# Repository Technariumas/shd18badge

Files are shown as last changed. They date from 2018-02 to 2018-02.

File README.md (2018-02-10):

# Science Hack Day Vilnius 2018 - badge

Participant badge for Science Hack Day Vilnius 2018

## Prerequisites

To use the badge, you will need the following:

 * A laptop with Linux, Mac OS or Windows and at least one free USB port.
 * If it’s Windows or Mac OS, make sure to install [drivers](https://wiki.wemos.cc/downloads) for the CH340 UBS2TTL chip.
 * A micro-USB cable with data lines that fits your USB port.
 * You will need a terminal application installed. For Linux and Mac you can use screen, which is installed by default. For Windows we recommend [PuTTy](http://www.chiark.greenend.org.uk/~sgtatham/putty/download.html) or [CoolTerm](http://freeware.the-meiers.org/).
 * Please note that the workshop will be in English.

## Schematics



## Programming

Use dmesg to determine the USB port the badge is connected to, e.g. /dev/ttyUSB0.

Flash the firmware:
cd shd18badge/micropython

Edit the flash_microcontroller.sh file so that it points to the correct USB port. If esptool.py is needed, install it (for example, pip install esptool.py). Then copy the Python files to the microcontroller:

python transfer_files.py -p /dev/ttyUSB5 -b 115200 util.py main.py thermistor.py boot.py
 
## Tutorial
 * A pretty great [tutorial is available here](http://docs.micropython.org/en/latest/esp8266/esp8266/tutorial/index.html)
 * [A MAC user first hand experience](MACUSERS.md) using the badge

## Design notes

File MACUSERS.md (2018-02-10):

## Experiences of a mac user getting the Tardigrade set up

1. Install drivers as per [the README](README.md). 
2. Open a terminal, plug the tardigrade in to your computer, and run `sudo dmesg` in the terminal. 
3. You should see a line like this, or something similar: `wch_usb detach. provider USB2.0-Serial.` - if not, unplug the tardigrade and plug it back in again before re-running `sudo dmesg`.
4. We now know we're looking for a device called wch_usb. run `ls /dev/tty.wchusb` and press tab to get the exact device name. It might be `/dev/tty.wchusbserial1410`.
5. Ok, we're ready to connect to the device! We'll open a session using the program called *screen*. Type `screen /dev/tty.wchusbyourdevice here  115200` - for me it was `screen /dev/tty.wchusbserial1410  115200`. 
6. After a few seconds, you should start seeing the temperature being output continuously to the screen now. Try putting your finger on the temperatures sensor (bottom middle of the tardigrade on the LED side) and watch the numbers change!
7. Press ctrl+c on your keyboard to stop the temperature output. Now you'll have a command prompt where you can type commands to your tardigrade. 
8. Try some commands like `flash(200)`, `getTemperature`, `setPixel(255,0,100)`, `setLeds(0b10101010)`, or `wigglefeet`. You can see the full list here: https://github.com/Technariumas/shd18badge/blob/master/micropython/main.py 

Some more tips:

- press ctrl+d to start the temperature readings again
- press ctrl+a+d to detach from the screen session and get your terminal window back.
- if you want to go back to the screen session and you haven't unplugged your tardigrade, type `screen -dr` to start playing with your tardigrade again. 

## setLeds:

You'll always need to leave 0b there, but try changing `01010101` to something else - there's one number for each tardigrade foot, and you can switch them all off by setting them to 0, e.g. `setLeds(0b00000000)`. Can you guess how to turn them all on?

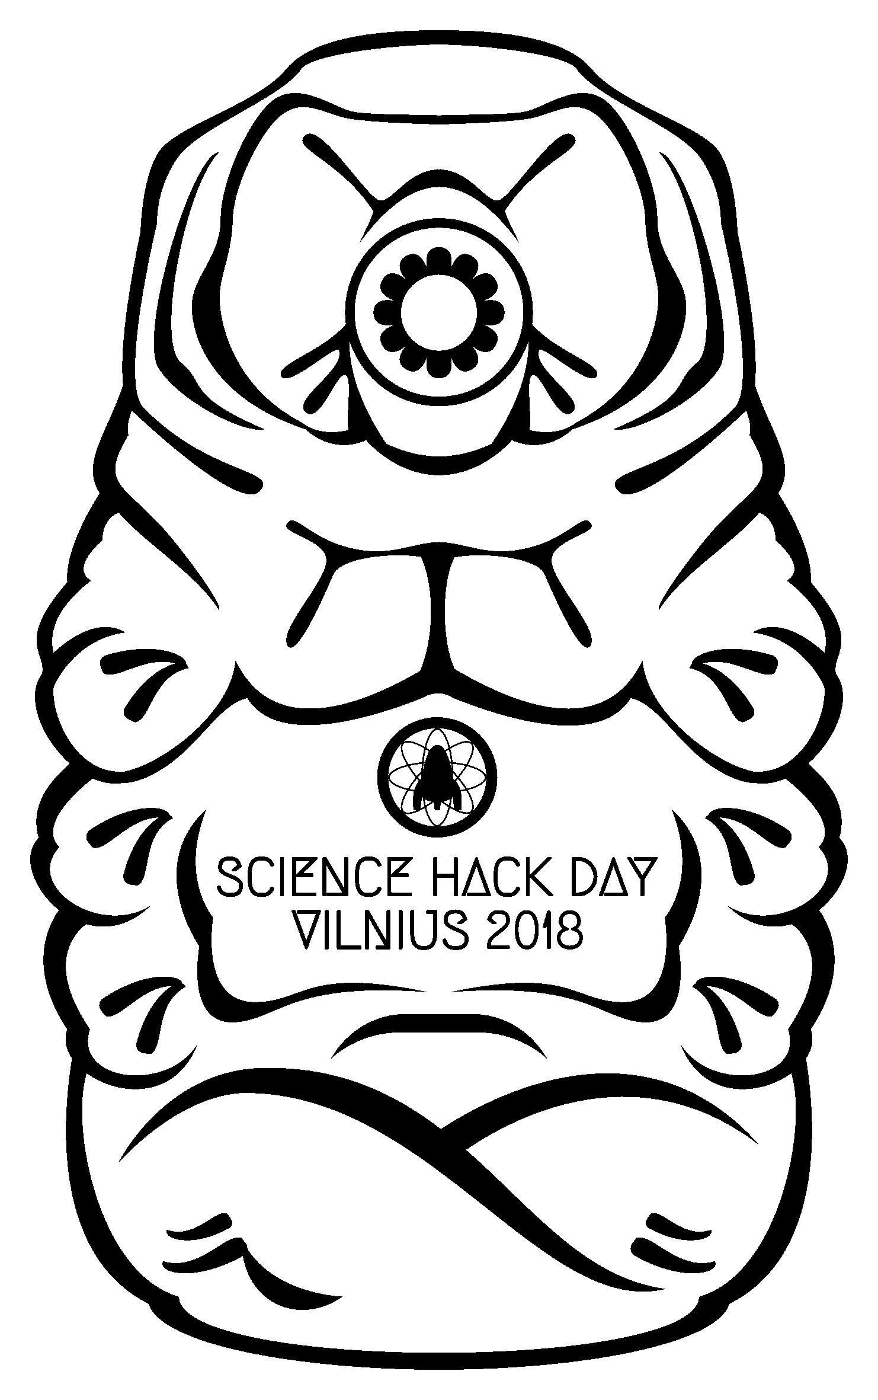
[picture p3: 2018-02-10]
letunai-10.svg.png

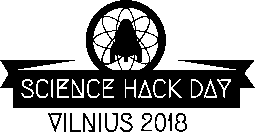
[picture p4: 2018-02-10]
g10385.png

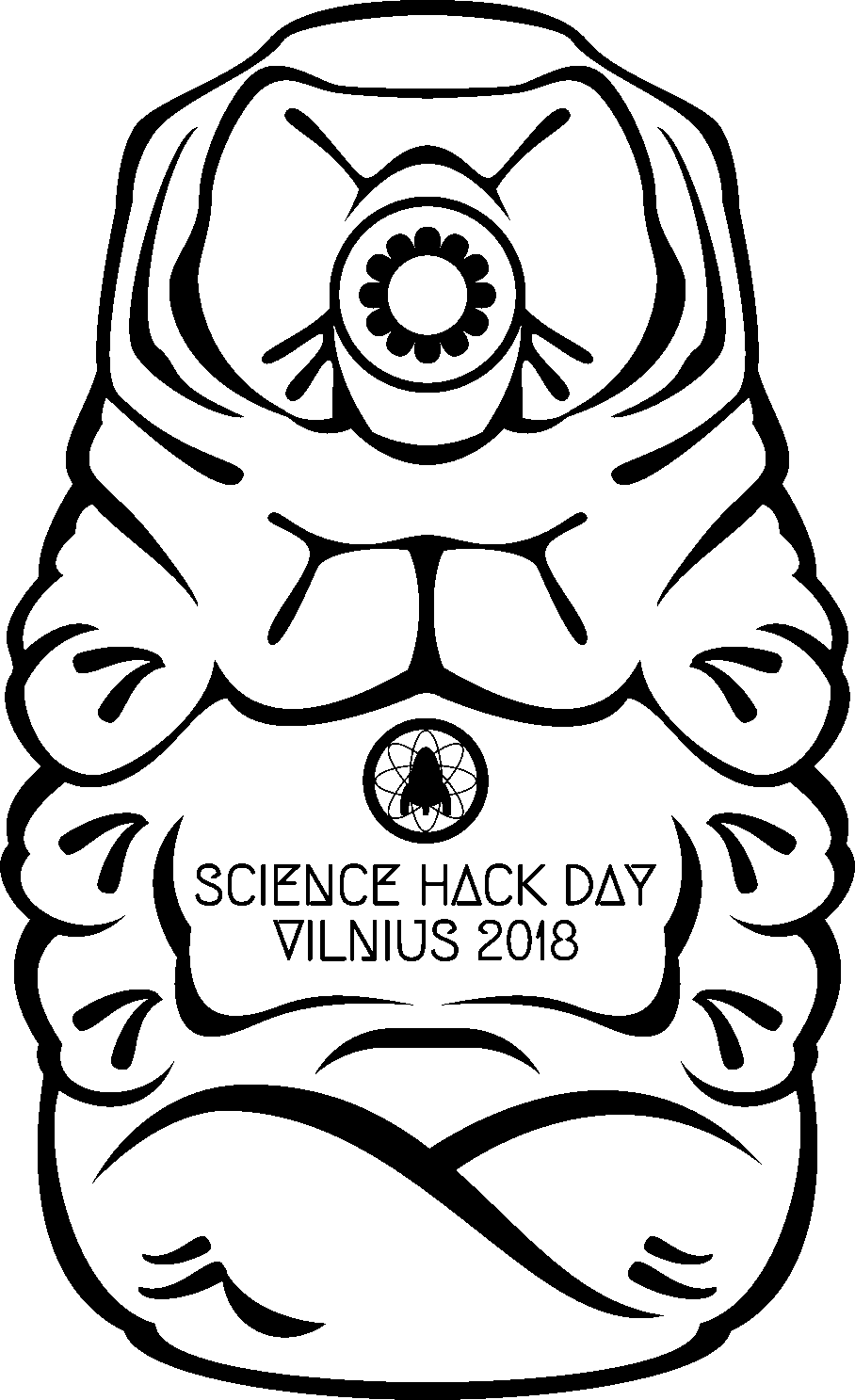
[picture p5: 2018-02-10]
letunas-10.png

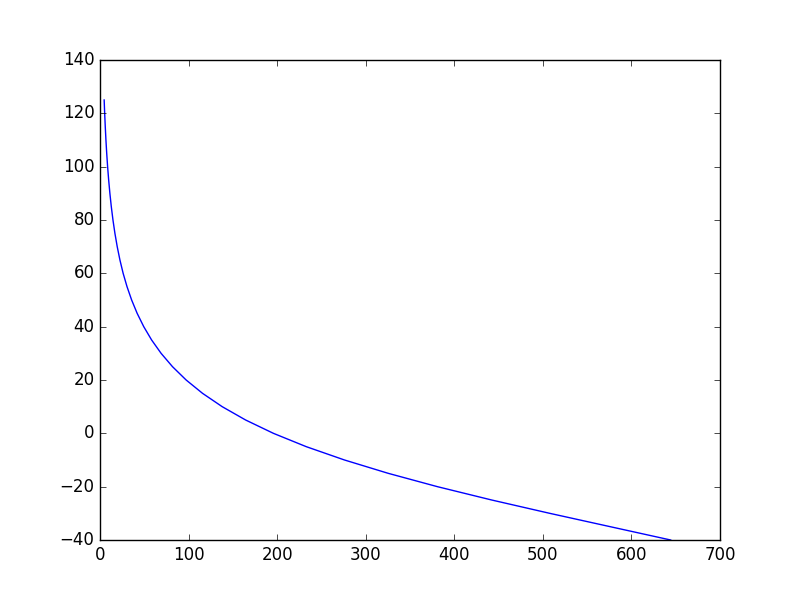
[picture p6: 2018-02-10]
micropython/adc-vs-temp.png

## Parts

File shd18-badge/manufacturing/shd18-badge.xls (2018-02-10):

Reference | Quantity | Value | Footprint | Datasheet | PartNo | Manufacturer | Distributor | Notes
BT1 | 1 | Battery | Battery_Holders:Keystone_2479_3xAAA |  | BH-2479 | ? | ?
C1 C2 | 2 | 1u | Capacitors_SMD:C_0603 |  | ? | ? | ? | 10V 1uF 0603
D1 D2 D3 D4 D5 D6 D7 D8 | 8 | LED | LEDs:LED_0603 |  | 19-217SUGC/TR8 | ? | ? | High brightness green led
LED1 | 1 | WS2812B | LEDs:LED_WS2812B-PLCC4 | http://www.world-semi.com/uploads/soft/150522/1-150522091P5.pdf | WS2812B | ? | ?
MK1 | 1 | Mounting_Hole | Mounting_Holes:MountingHole_3.2mm_M3 |  | ? | ? | ? | DNP
R1 | 1 | R | Resistors_SMD:R_0603 |  | ? | ? | ? | 1.00%
R10 R2 R3 R4 R5 R6 R7 R8 R9 | 9 | 1k | Resistors_SMD:R_0603 |  | ? | ? | ? | 1.00%
SW1 | 1 | SW_SPDT | wemos:SWITCH-SPST-SMD-A |  | ? | ? | ?
SW2 | 1 | SW_Push | wemos:4P-SMD-6.2X6.2X4H |  | ? | ? | ?
TH1 | 1 | Thermistor | Resistors_SMD:R_0603 |  | ? | ? | ? | 10k thermistor
U1 | 1 | WeMos_mini | wemos:D1_mini_board | https://wiki.wemos.cc/products:d1:d1_mini | ? | ? | ? | Wemos Mini board, use female headers.
U2 | 1 | 74HC595 | Housings_SOIC:SOIC-16_3.9x9.9mm_Pitch1.27mm | http://www.nxp.com/documents/data_sheet/74HC_HCT595.pdf | ? | ? | ? | Power voltage range down to 2V or lower

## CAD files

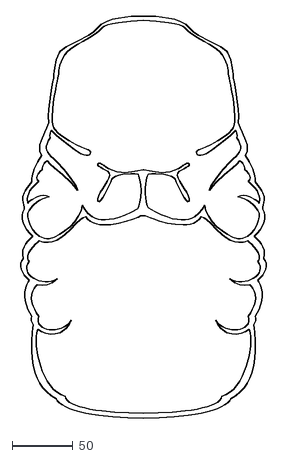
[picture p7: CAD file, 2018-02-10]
drawing1.dxf
209.5 x 330.9

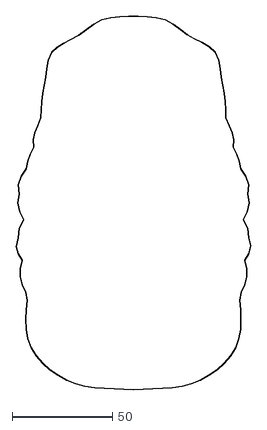
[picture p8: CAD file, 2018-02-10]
ooo.dxf
117.0 x 186.5

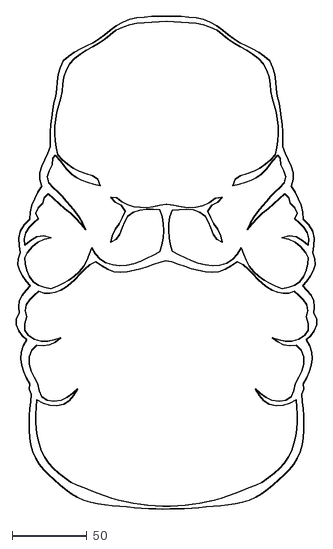
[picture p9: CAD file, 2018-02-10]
outline2.dxf
201.5 x 330.5

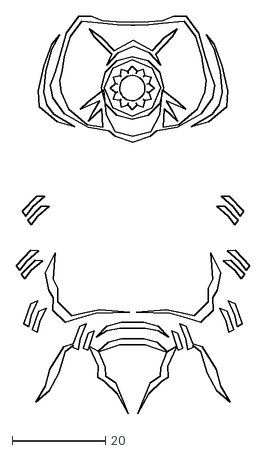
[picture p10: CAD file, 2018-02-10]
kisakita-10.dxf
50.2 x 85.5

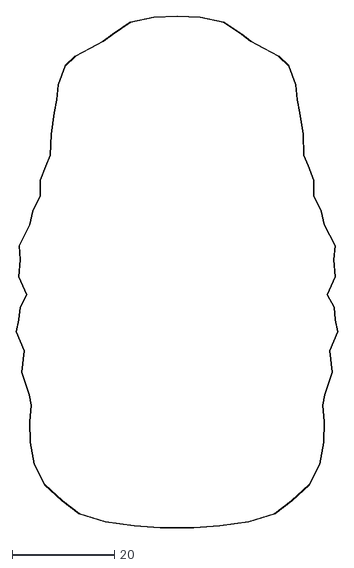
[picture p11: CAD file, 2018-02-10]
outline-10.dxf
62.9 x 100.3

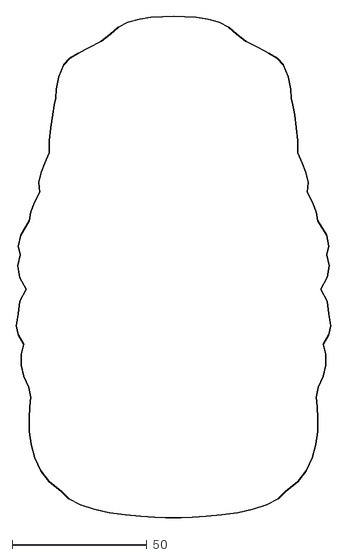
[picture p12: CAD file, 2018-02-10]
outline.dxf
116.6 x 185.7

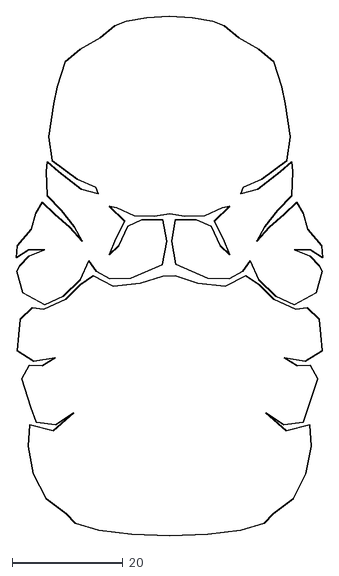
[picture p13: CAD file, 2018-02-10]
raukai-10.dxf
55.3 x 93.7

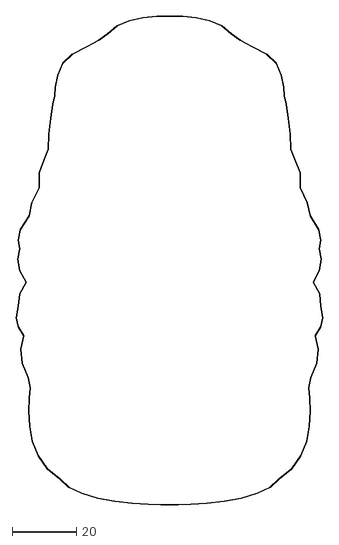
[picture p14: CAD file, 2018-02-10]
outline-10-1.dxf
95.6 x 152.4

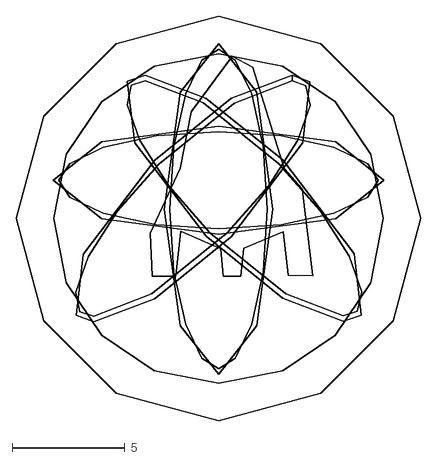
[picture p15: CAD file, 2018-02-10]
raketa.dxf
17.9 x 17.9

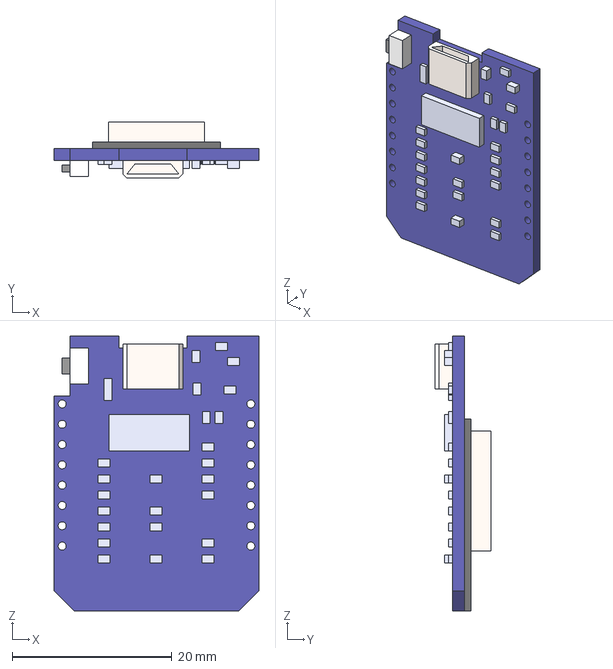
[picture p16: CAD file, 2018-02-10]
WEMOS D1 mini.step
25.6 x 7.00 x 34.4 mm

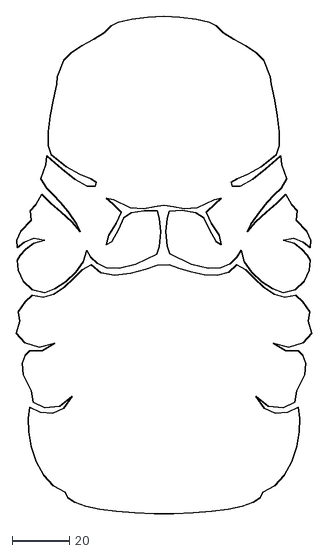
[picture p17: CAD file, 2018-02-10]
raukai.dxf
103.0 x 173.5

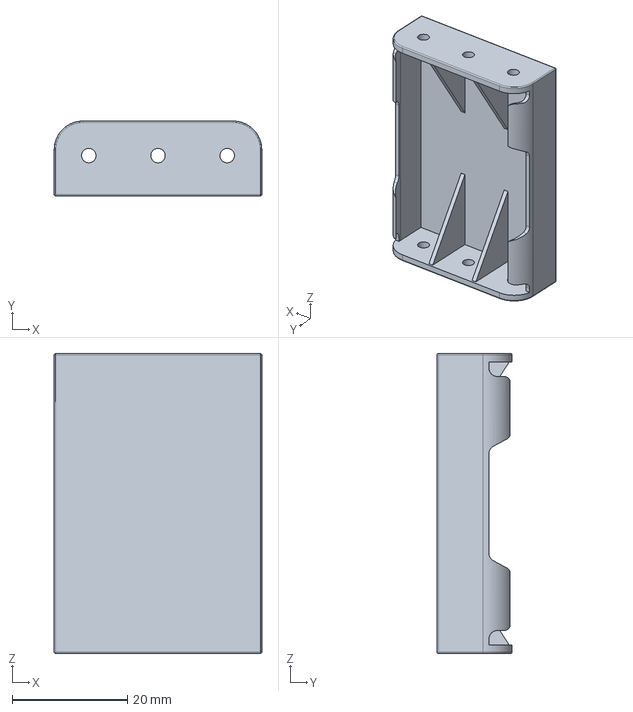
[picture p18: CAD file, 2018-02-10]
3x AAA battery holder.stp
36.0 x 13.0 x 52.0 mm

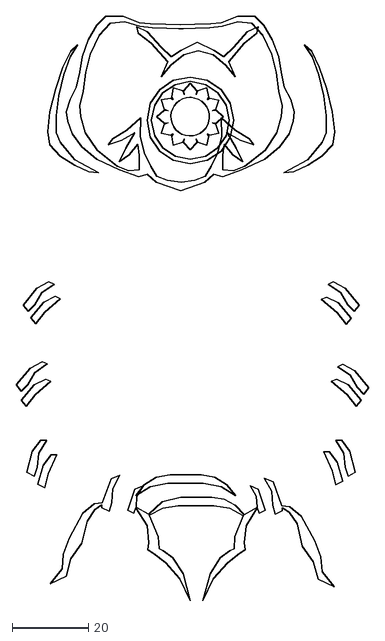
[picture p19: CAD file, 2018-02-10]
kisakita.dxf
92.1 x 152.9

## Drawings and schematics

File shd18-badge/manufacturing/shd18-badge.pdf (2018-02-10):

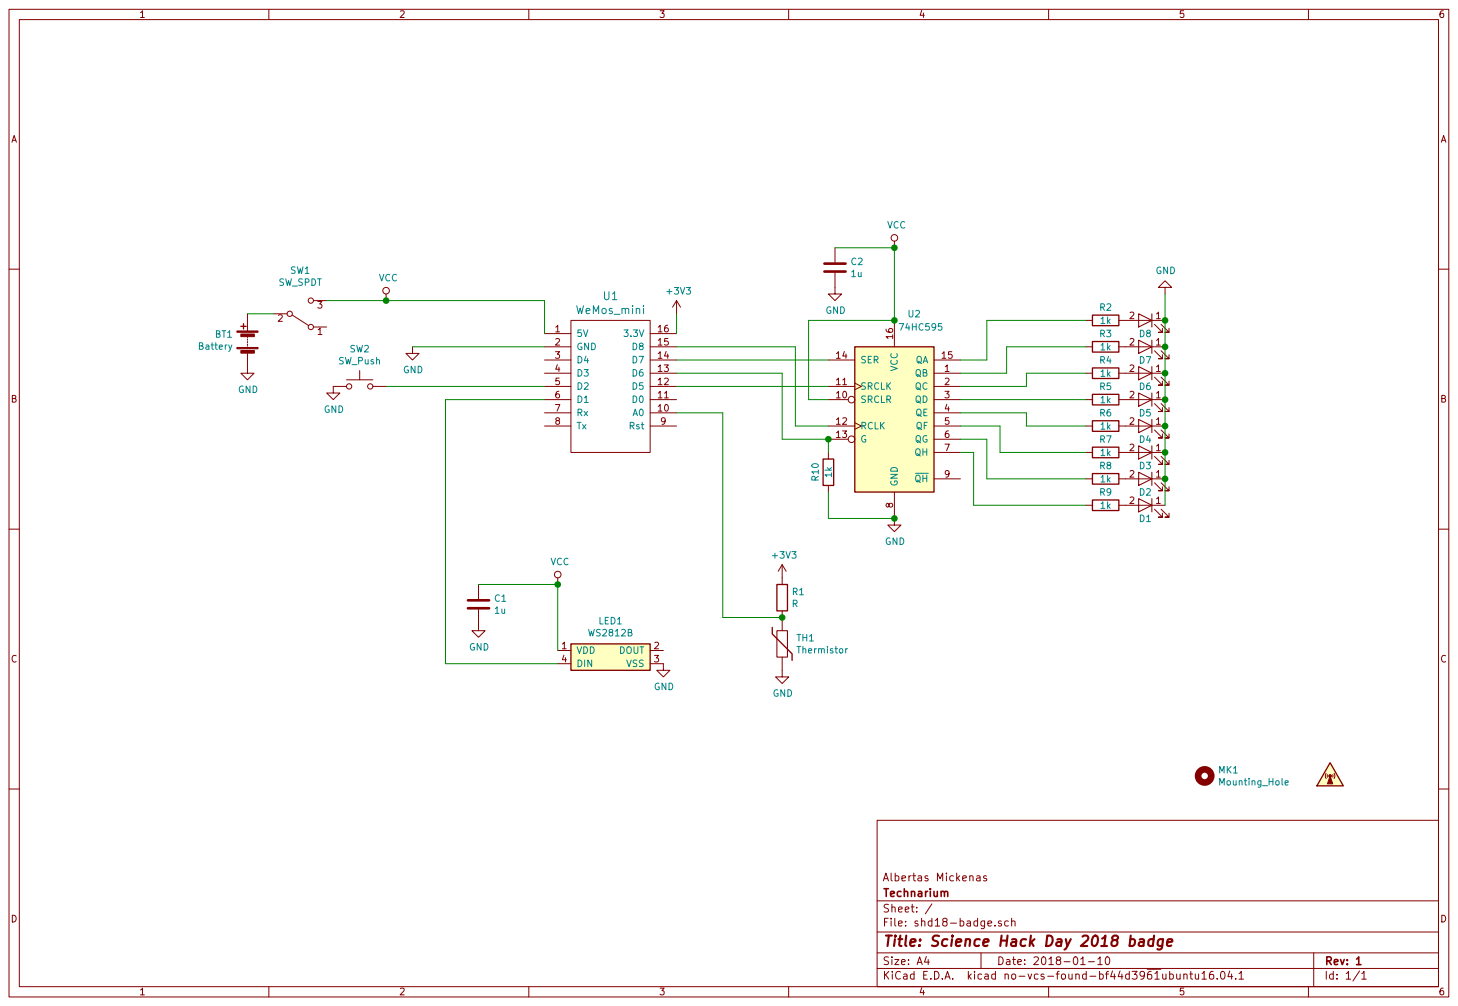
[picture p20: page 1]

8 QH 9 SRCLR 10 SRCLK 11 RCLK 12 G

Albertas Mickenas
File: shd18-badge.sch Sheet: / Technarium

Id: 1/1 Title: Science Hack Day 2018 badge

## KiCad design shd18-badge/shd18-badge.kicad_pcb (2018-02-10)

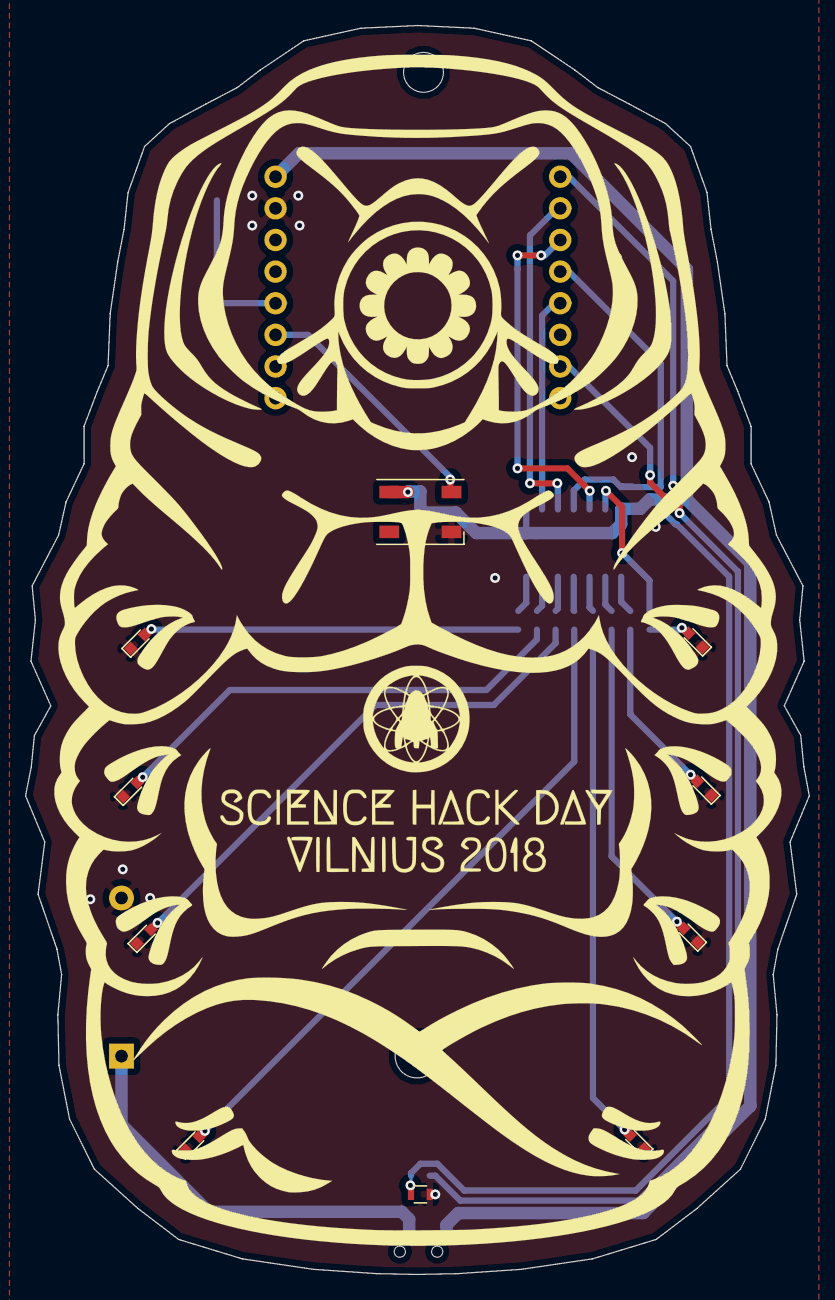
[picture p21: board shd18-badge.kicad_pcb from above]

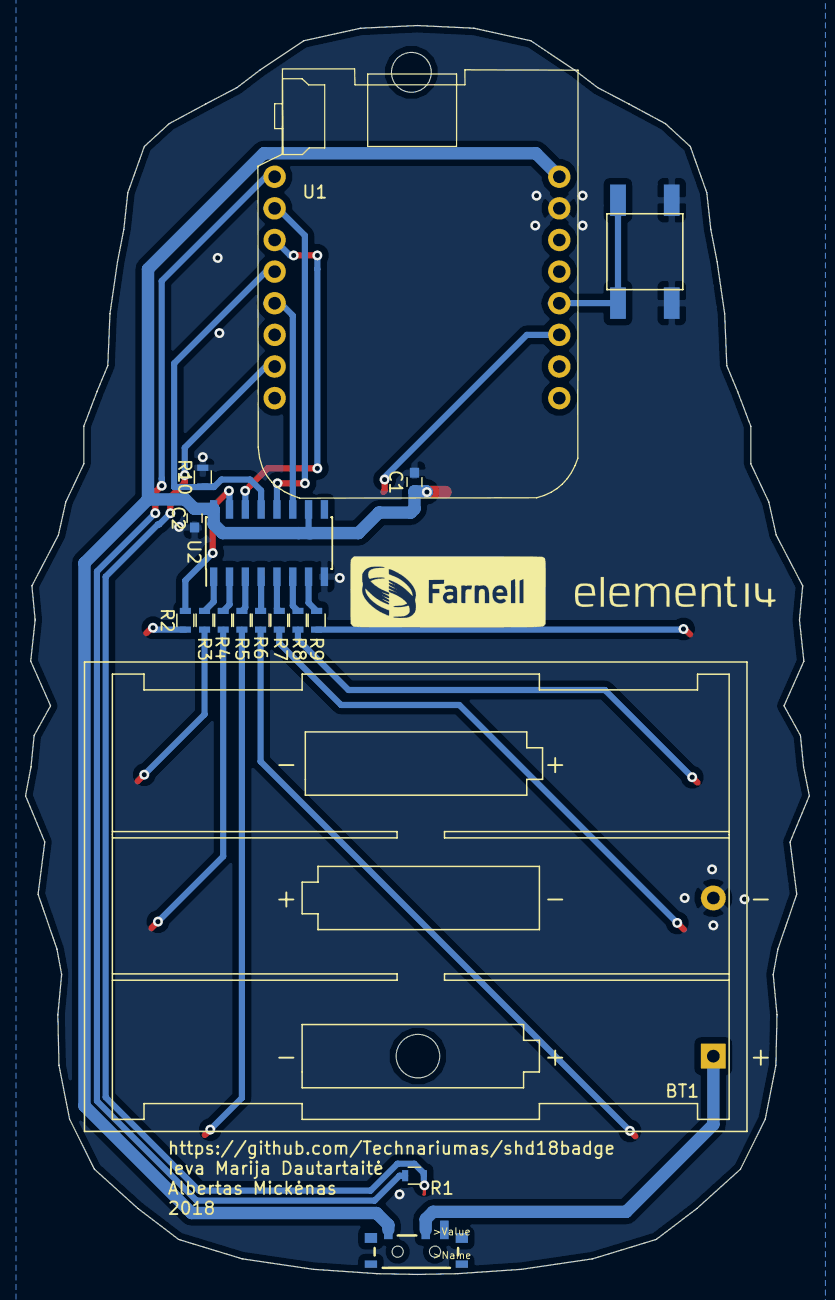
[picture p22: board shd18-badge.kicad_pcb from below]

Board: 2 copper layers, 62.9 x 100.3 mm, 28 parts (17 on the bottom side), 27 nets.

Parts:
BT1: Battery; Keystone_2479_3xAAA
C1, C2: 1u; C_0603
D1, D2, D3, D4, D5, D6, D7, D8: LED; LED_0603
LED1: WS2812B; LED_WS2812B-PLCC4
MK1: Mounting_Hole; MountingHole_3.2mm_M3
R1: R; R_0603
R2, R3, R4, R5, R6, R7, R8, R9, R10: 1k; R_0603
SW1: SW_SPDT; SWITCH-SPST-SMD-A
SW2: SW_Push; 4P-SMD-6.2X6.2X4H
TH1: Thermistor; R_0603
U1: WeMos_mini; D1_mini_board
U2: 74HC595; SOIC-16_3.9x9.9mm_Pitch1.27mm

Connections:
+3V3: R1.1, U1.16
GND: BT1.2, C1.2, C2.2, D1.1, D2.1, D3.1, D4.1, D5.1, D6.1, D7.1, D8.1, LED1.3, R10.2, SW2.1, TH1.2, U1.2, U2.8
unnamed: BT1.1, SW1.2
unnamed: D1.2, R9.1
unnamed: D2.2, R8.1
unnamed: D3.2, R7.1
unnamed: D4.2, R6.1
unnamed: D5.2, R5.1
unnamed: D6.2, R4.1
unnamed: D7.2, R3.1
unnamed: D8.2, R2.1
unnamed: LED1.4, U1.6
unnamed: R1.2, TH1.1, U1.10
unnamed: R2.2, U2.15
unnamed: R3.2, U2.1
unnamed: R4.2, U2.2
unnamed: R5.2, U2.3
unnamed: R6.2, U2.4
unnamed: R7.2, U2.5
unnamed: R8.2, U2.6
unnamed: R9.2, U2.7
unnamed: R10.1, U1.13, U2.13
unnamed: SW2.2, U1.5
unnamed: U1.12, U2.11
unnamed: U1.14, U2.14
unnamed: U1.15, U2.12
VCC: C1.1, C2.1, LED1.1, SW1.3, U1.1, U2.10, U2.16

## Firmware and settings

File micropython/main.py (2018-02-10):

from machine import Pin, SPI, ADC
from neopixel import NeoPixel
from time import sleep
import thermistor
import urandom
import util


pixel = NeoPixel(Pin(5, Pin.OUT), 1)
spi = SPI(1, baudrate=1000000, polarity=0, phase=0)
cs=Pin(15, Pin.OUT)
thermistorAdc = ADC(0)
button = Pin(4, Pin.IN, Pin.PULL_UP)

def setPixel(r, g, b):
	pixel[0] = (r, g, b)
	pixel.write()         

def setLeds(b):
	cs.off();
	spi.write(bytearray([b]))
	cs.on();

def getTemperature():
	return thermistor.lsbToTemperature(thermistorAdc.read())



def wiggleFeet():
	for t in range(10):
		setLeds(0x55)
		sleep(0.07)
		setLeds(0xAA)
		sleep(0.07)
	setLeds(0)

def cycleFeet():
	for t in range(8):
		setLeds(1 << t)
		sleep(0.1)


def flash(color):
	if None == color:
		color = urandom.getrandbits(8)
	(r, g, b) = util.colorWheel(color)
	setPixel(r, g, b)
	while r > 0 or g > 0 or b > 0:
		if r > 0:
			r = r - 1
		if g > 0:
			g = g - 1
		if b > 0:
			b = b - 1
		setPixel(r, g, b)
		sleep(0.01)

setPixel(0, 0, 0)
wiggleFeet()
flash(None)
cycleFeet()
cycleFeet()
cycleFeet()


temp = getTemperature()
MODE1 = 1
MODE2 = 2

mode = MODE1

while True:
	print(getTemperature())

	if MODE1 == mode:
		if abs(getTemperature() - temp) > 1:
			flash(int(util.translate(temp, 5, 30, 0, 255)))
			sleep(0.1)
			temp = getTemperature()
		setLeds(urandom.getrandbits(8))
		sleep(0.01)
	elif MODE2 == mode:
		temp = getTemperature()
		(r,g,b) = util.colorWheel(int(util.translate(temp, 5, 30, 0, 255)))
		setPixel(r, g, b)
		cycleFeet()

	if 0 == button.value():
		setPixel(0,0,0)
		setLeds(0)
		if mode < MODE2:
			mode = mode + 1
		else:
			mode = MODE1
		while 0 == button.value():
			print(button.value())

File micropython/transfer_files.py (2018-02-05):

import websocket
import serial
import sys
import time
import os
import binascii
import tqdm


CHUNK_SIZE = 50
TEST_PY = False


def ctrl(key):
    return chr(ord(key.upper()) - ord('A') + 1)



class EspSerial(serial.Serial):
    DEFAULT_DELAY = .1
    def command(self, data='', delay=None):
        delay = delay or self.DEFAULT_DELAY
        self.write(data + '\r')
        time.sleep(delay)
        res = self.read(self.inWaiting())
        #sys.stdout.write(res)
        print 'RES', repr(res)
        return res

    def reset_esp(self):
        self.write(ctrl('c'))
        self.command(ctrl('d'), 1.5)
        self.command()
        assert not self.command().endswith('>>> '), 'Bad reset!'

    def prepare_transfer(self):
        self.write(ctrl('c'))
        self.command('import ubinascii')
        self.write(ctrl('e'))
        self.write('def w(d):\n')
        self.write('    return f.write(ubinascii.a2b_base64(d))\n')
        self.write(ctrl('d'))
        self.command()
    
    def transfer_chunk(self, chunk):
        assert len(chunk) <= CHUNK_SIZE, 'Chunk is too big!'
        return '...' not in self.command("w('%s')" % binascii.b2a_base64(chunk))


#class EspWebSocket(websocket.WebSocket, MyEsp):
#    DEFAULT_DELAY = 0
#
#    write = websocket.WebSocket.send
#    read_all = websocket.WebSocket.recv
#
#    def __init__(self, url, password):
#        super(EspWebSocket, self).__init__()
#        self.connect(url)
#        self.read_all()
#        self.command(password)


def work(sources, webrepl_url, webrepl_password, uart_port_name, uart_baud=115200):
    try:
#        if webrepl_url:
#            port = EspWebSocket(webrepl_url, webrepl_password)
#        else:
        port = EspSerial(uart_port_name, uart_baud)

        #print 'Performing reset...'
        #port.reset_esp()

        print 'Preparing...'
        port.prepare_transfer()

        for source_path in sources:
            dest_path = os.path.split(source_path)[1]
            try:
                port.command("f = open('%s', 'wb')" % dest_path)

                progress_bar = tqdm.tqdm(ncols=100, desc=source_path, total=os.stat(source_path).st_size, unit='B', unit_scale=True)

                with open(source_path, 'rb') as in_f:
                    while True:
                        buf = in_f.read(CHUNK_SIZE)
                        if not buf:
                            break
                        if not port.transfer_chunk(buf):
                            # TODO: Try again with higher command delay
                            progress_bar.close()
                            print '%s FAILED!' % source_path
                            port.write('\x03')
                            break
                        progress_bar.update(len(buf))
            except Exception as e:
                print e
            finally:
                progress_bar.close()
                port.command('f.close()')
    except Exception as e:
        print e
    finally:
        time.sleep(1)
        port.reset_esp()
        port.close()

    print 'Done.'


def main():
    import argparse

    parser = argparse.ArgumentParser()

    parser.add_argument('-u', '--url', help='WebREPL URL')
    parser.add_argument('-w', '--password', help='WebREPL password')
    parser.add_argument('-p', '--port', help='UART port name')
    parser.add_argument('-b', '--baud', help='UART baud rate', type=int, default=115200)
    parser.add_argument('sources', help='Files to transfer', nargs='+')

    args = parser.parse_args()

#    sys.stderr.encoding = 'utf8'

    work(args.sources, args.url, args.password, args.port, args.baud)

if __name__ == '__main__':
    main()

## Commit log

2018-01-10 Add some text to README, add schematics
2018-01-29 Add links to helper apps and drivers
2018-02-05 Fix the upload script, add more blinking
    [main.py, transfer_files.py]
2018-02-06 Add thermistor conversion to temperature, disable networking on boot
2018-02-10 add all the rest
    [3x AAA battery holder.stp, WEMOS D1 mini.step, drawing1.dxf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]
